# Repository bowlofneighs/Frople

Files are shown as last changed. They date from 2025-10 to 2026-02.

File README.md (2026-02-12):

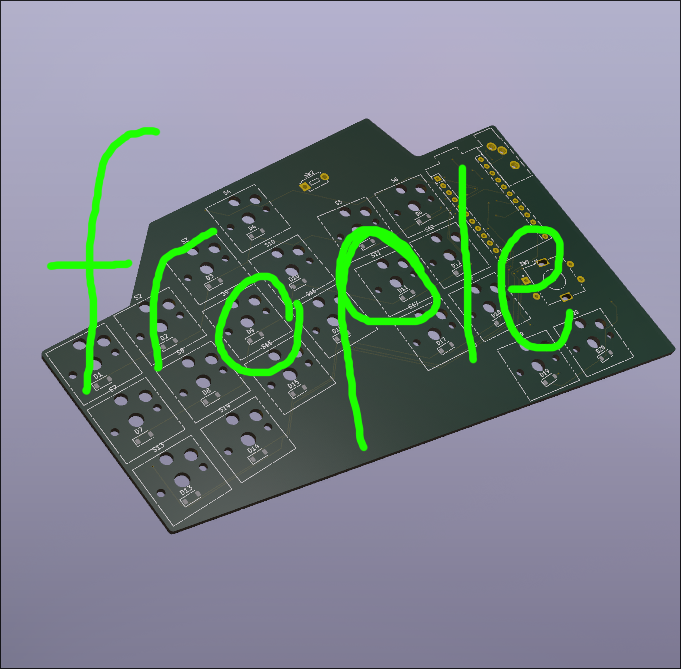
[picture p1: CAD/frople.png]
Frople


# frople
Frople is a split ergonomic keyboard with a 40 key layout. It utilizes a 6x3 main matrix and a 2x1 thumbfan on each side. It uses 2 Arduino Pro Micros as its MCUs and QMK for the firmware. The keys were designed specifically with my hand dimensions in mind, seeing as I took measurements of my finger-length to decide the key stagger. It will take advantage of home-row-mods to allow me to still use my mod keys with such a small key footprint. It also has extra layers to account for the keys that could not fit on the main layer. It uses a TRS cable to communicate between the two halves of the keyboard using serial communcation. In the future it could theoretically be upgraded with a Nice!Nano V2 to allow for wireless communication between the two halves and the computer through BLE (bluetooth low energy). However my current computer does not have bluetooth and the Nice!Nano V2 was more expensive than the Arduino Pro Micro and as such I went with the Pro Micro for the MCU.

I built Frople because I have always been interested by those desktop setup videos, they seemed really cool, and I thought that a split keyboard would be a way to take my desk to the next level. I also made it because I tried out home-row-mods on my normal keyboard using a software called [Kanata](https://github.com/jtroo/kanata) and I found that it really increased my power-useriness and I wanted to take that to the next level. I also am really unsatisfied with my current keyboard, especially the lack of linux compatibal firmware. The final reason I wanted to make a split keyboard is because it sounded like a really fun project to get into hardware design with.



|Item |Description |Quantity |Unit Price CAD |Unit Price USD|Price + tax * quantity (CAD)|Price + tax * quantity (USD)|Shipping CAD |shipping USD|Note |Link |
|---|---|---|---|---|---|---|---|---|---|---|
|Red Choc Switches |Key Switches |40pcs |29.41 + 3.82(tax)|23.93USD |33.23 |23.93 USD |FREE |FREE | |https://www.aliexpress.com/item/1005008751312031.html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 |
|Kailh Hot Swap sockets|Hot swaps |1 (they come in packs of 100 :hs:)|12.87 + 1.67(tax)|10.47 USD |14.54 |10.47 USD |FREE |FREE |even though it was 100 they were still the cheapest |https://www.aliexpress.com/item/1005006625852715.html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 |
|Arduino Pro Micro |MCU |2 |8.99 + 1.16 |7.31 USD |20.3 |14.62 USD |FREE |FREE | |https://www.aliexpress.com/item/1005008804370504.html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 |
|Keycaps |choc low profile ldsa keycaps|4 they come in packs of 10 |5 + 0.65 |4.06 USD |22.6 |16.27 USD |10 + 1.3 |8.13USD |I couldn’t find cheaper unmarked keycaps on aliexpress|https://lowprokb.ca/collections/keycaps/products/ldsa-low-profile-blank-keycaps?variant=44790995878052 |
|SJ1-3533NG |TRS audio jack |2 |3.15 + 0.40 |2.55 USD |7.1 |5.11 USD |5.54 + 0.72 |4.50 USD |LCSC was much more expensive bc shipping |https://www.aliexpress.com/item/1005007818050385.html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{%22order%22%3A%221%22%2C%22eval%22%3A%221%22%2C%22fromPage%22%3A%22search%22}&pdp_npi=6%40dis!CAD!3.15!3.15!!!15.45!15.45!%402101c44517685003345927398e8be0!12000042315760823!sea!CA!0!ABX!1!0!n_tag%3A-29910%3Bd%3A53760023%3Bm03_new_user%3A-29895&curPageLogUid=4tlGIj6PnRZU&utparam-url=scene%3Asearch&#124;query_from%3A&#124;x_object_id%3A1005007818050385&#124;_p_origin_prod%3A|
|PCB |keyboard pcb |1 | |19.00 USD | |19.00 USD | |13.25 USD | |https://hc-cdn.hel1.your-objectstorage.com/s/v3/6d1642395864fce0_image.png |
|ec-11 |rotary encoder |1 They come in packs of 5 |1.62 + 0.21 |1.31 USD |1.83 |1.31 USD |FREE |FREE | |https://www.aliexpress.com/item/1005003824684681.html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 |
| | | | | | | | | | | |
|Total | | | | |99.6 CAD (not including pcb)|90.71 USD |17.56 (Not including pcb)|25.88 |full cost:: 116.59 USD | |

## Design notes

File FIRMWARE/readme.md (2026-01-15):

# frople

frople

*A short description of the keyboard/project*

* Keyboard Maintainer: [Bowlofneighs](https://github.com/Bowlofneighs)
* Hardware Supported: *The PCBs, controllers supported*
* Hardware Availability: *Links to where you can find this hardware*

Make example for this keyboard (after setting up your build environment):

    make frople:default

Flashing example for this keyboard:

    make frople:default:flash

See the [build environment setup](https://docs.qmk.fm/#/getting_started_build_tools) and the [make instructions](https://docs.qmk.fm/#/getting_started_make_guide) for more information. Brand new to QMK? Start with our [Complete Newbs Guide](https://docs.qmk.fm/#/newbs).

## Bootloader

Enter the bootloader in 3 ways:

* **Bootmagic reset**: Hold down the key at (0,0) in the matrix (usually the top left key or Escape) and plug in the keyboard
* **Physical reset button**: Briefly press the button on the back of the PCB - some may have pads you must short instead
* **Keycode in layout**: Press the key mapped to `QK_BOOT` if it is available

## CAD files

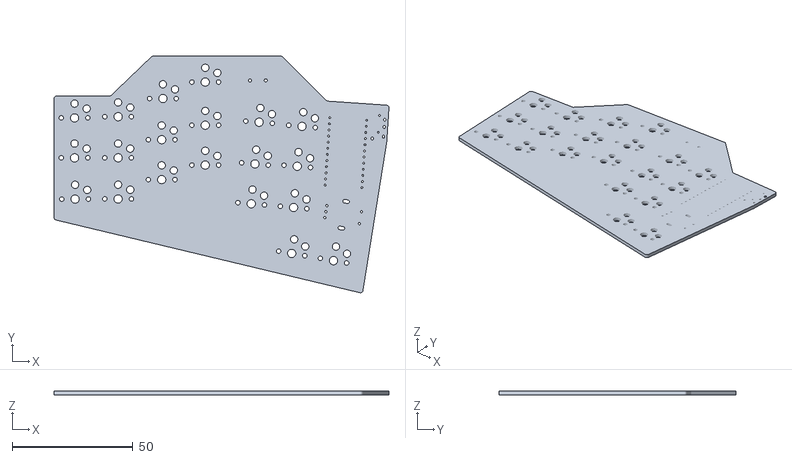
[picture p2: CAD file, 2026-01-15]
Main/MainFill.stl
138.4 x 97.8 x 1.51

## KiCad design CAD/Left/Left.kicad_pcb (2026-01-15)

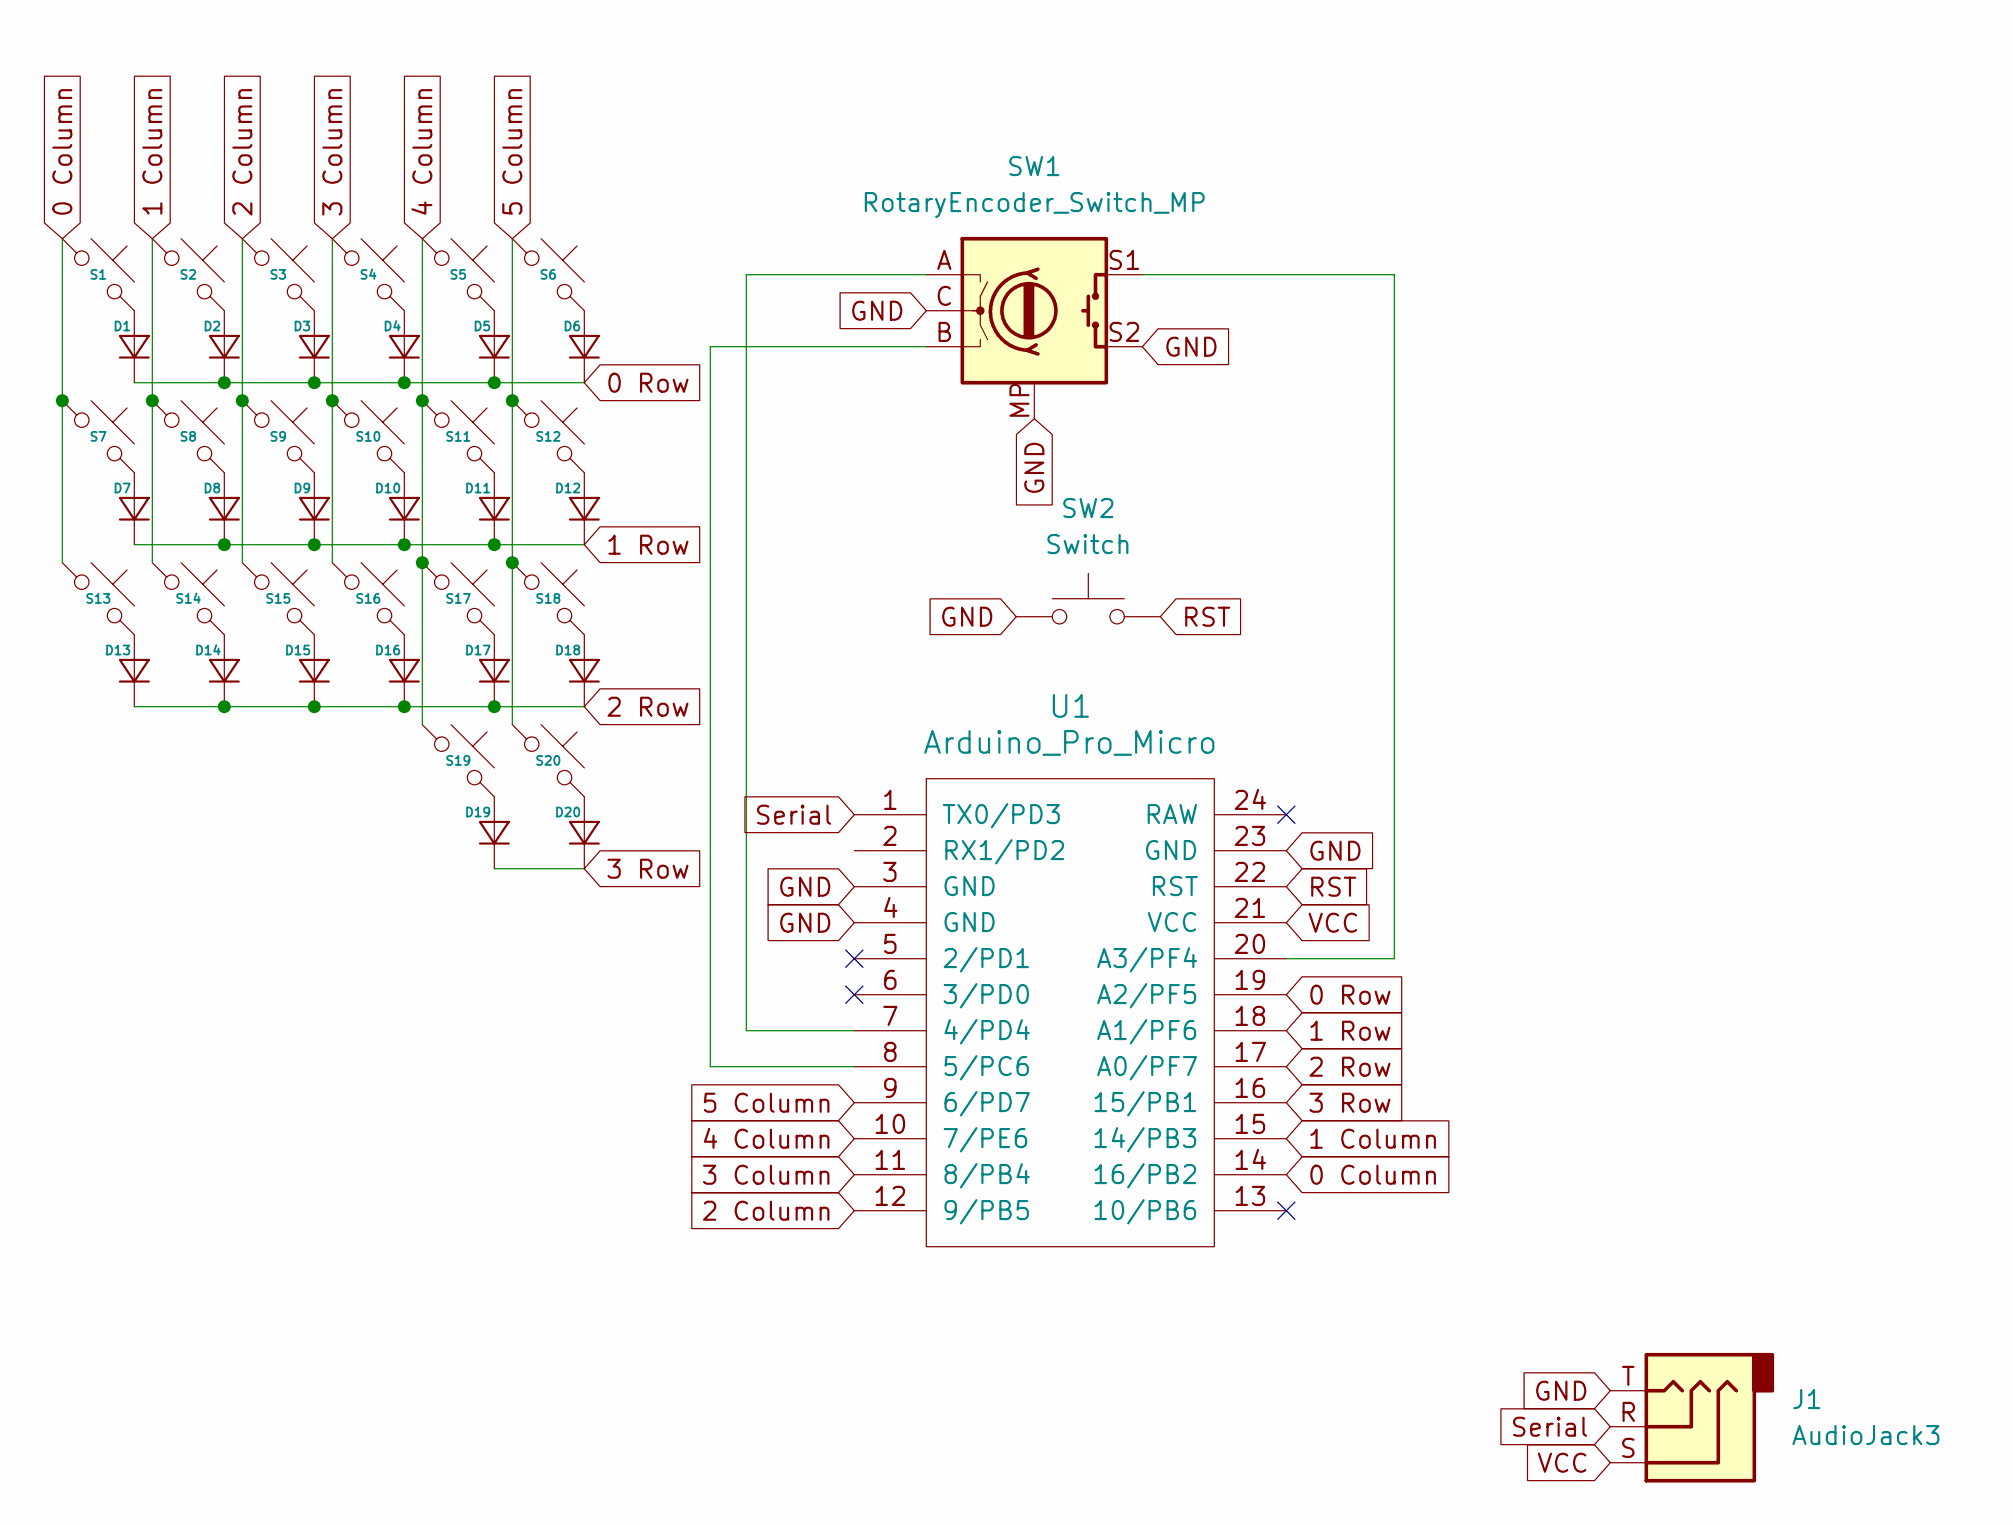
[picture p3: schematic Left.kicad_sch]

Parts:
D1, D2, D3, D4, D5, D6, D7, D8, D9, D10, D11, D12, D13, D14, D15, D16, D17, D18, D19, D20: D_SOD-123
J1: AudioJack3; Jack_3.5mm_CUI_SJ1-3533NG_Horizontal_CircularHoles
S1, S2, S3, S4, S5, S6, S7, S8, S9, S10, S11, S12, S13, S14, S15, S16, S17, S18, S19, S20: Hotswap_Choc_V1
SW1: RotaryEncoder_Switch_MP; RotaryEncoder_Alps_EC11E-Switch_Vertical_H20mm
SW2: Switch; Button_MJTP1243
U1: Arduino_Pro_Micro; Sparkfun_Pro_Micro

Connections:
0 Column: S1.1, S7.1, S13.1, U1.14 (16/PB2)
0 Row: D1.1 (K), D2.1 (K), D3.1 (K), D4.1 (K), D5.1 (K), D6.1 (K), U1.19 (A2/PF5)
1 Column: S2.1, S8.1, S14.1, U1.15 (14/PB3)
1 Row: D7.1 (K), D8.1 (K), D9.1 (K), D10.1 (K), D11.1 (K), D12.1 (K), U1.18 (A1/PF6)
2 Column: S3.1, S9.1, S15.1, U1.12 (9/PB5)
2 Row: D13.1 (K), D14.1 (K), D15.1 (K), D16.1 (K), D17.1 (K), D18.1 (K), U1.17 (A0/PF7)
3 Column: S4.1, S10.1, S16.1, U1.11 (8/PB4)
3 Row: D19.1 (K), D20.1 (K), U1.16 (15/PB1)
4 Column: S5.1, S11.1, S17.1, S19.1, U1.10 (7/PE6)
5 Column: S6.1, S12.1, S18.1, S20.1, U1.9 (6/PD7)
GND: J1.T, SW1.C, SW1.MP, SW1.S2, SW2.1, U1.3 (GND), U1.4 (GND), U1.23 (GND)
unnamed: D1.2 (A), S1.2
unnamed: D2.2 (A), S2.2
unnamed: D3.2 (A), S3.2
unnamed: D4.2 (A), S4.2
unnamed: D5.2 (A), S5.2
unnamed: D6.2 (A), S6.2
unnamed: D7.2 (A), S7.2
unnamed: D8.2 (A), S8.2
unnamed: D9.2 (A), S9.2
unnamed: D10.2 (A), S10.2
unnamed: D11.2 (A), S11.2
unnamed: D12.2 (A), S12.2
unnamed: D13.2 (A), S13.2
unnamed: D14.2 (A), S14.2
unnamed: D15.2 (A), S15.2
unnamed: D16.2 (A), S16.2
unnamed: D17.2 (A), S17.2
unnamed: D18.2 (A), S18.2
unnamed: D19.2 (A), S19.2
unnamed: D20.2 (A), S20.2
unnamed: SW1.A, U1.7 (4/PD4)
unnamed: SW1.B, U1.8 (5/PC6)
unnamed: SW1.S1, U1.20 (A3/PF4)
RST: SW2.2, U1.22 (RST)
Serial: J1.R, U1.1 (TX0/PD3)
VCC: J1.S, U1.21 (VCC)

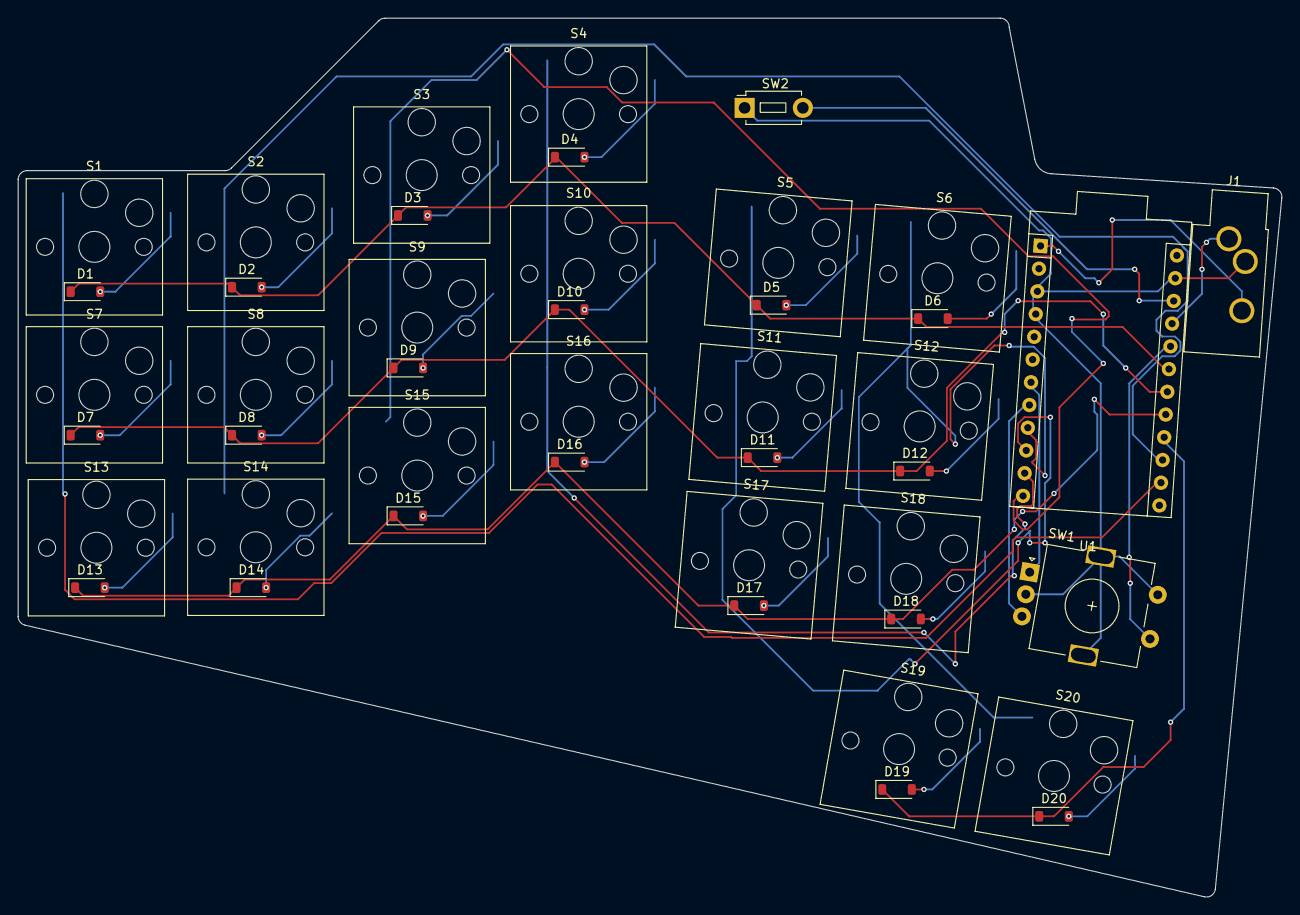
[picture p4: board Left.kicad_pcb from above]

Board: 2 copper layers, 140.9 x 98.0 mm, 44 parts (0 on the bottom side), 37 nets.

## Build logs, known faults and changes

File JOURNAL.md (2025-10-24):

<!--
  ===================    !!READ THIS NOTICE!!   ====================
  DO NOT edit this file manually. Your changes WILL BE OVERWRITTEN!
  This journal is auto generated and updated by Hack Club Blueprint.
  To edit this file, please edit your journal entries on Blueprint.
  ==================================================================
-->

## 10/13/2025 10 AM - Begun Design of key layout  

* Begun keyboard definition in ergogen
* read through FlatFootFox's "Lets Design a Keyboard" introduction and 1/4 of part 1 ( https://flatfootfox.com/ergogen-part1-units-points/ )
* Did research on implementing rotary encoder and/or sliding potentiometer into keyboard design; rotary encoder is feasable, sliding potentiometer is not



## 10/13/2025 5 PM - Designed keymap  





- Defined all the keys in ergogen
- came up with a 40 key layout (6x3 main body 1x2 thumbfan)
- Designed the keymap utilizing home-row-mods and special layers configurable in zmk. 
- I am planning on implementing Hyprland specific keybinds to the keymap to let me navigate my window manager faster

next steps:
- design key layout in ergogen for ergonomics
- brainstorm case designs  

## 10/15/2025 - Designed key layout  

- took measurements of my hands
- did research on how to use said measurements in keyboard layout
- made the keyboard layout using ergogen
- spent a while (not included in time estimate, it was like 30 minutes tho) configuring the GODDAMN PRINTER
- verified that there was no overlap between keys which is a bit harder (not much) than it sounds due to how ergogen renders keys
 

- printed out a couple tests for the key layout to make sure it felt good to type on

WhatsApp Image 2025-10-15 at 22.23.29.jpeg

- figured out how to push to github so now you can see my code on github (also not included in time estimate, it was like 30 minutes also, github CLI hates me)

## 10/16/2025 12 AM - Begun design of pcb  

- did research on part pricing
- started budgeting my build and researching keycaps, switches, encoders etc
- begun design and layout of pcb
- decided on a wired split design using a TRRS cable to communicate between each side
- have ideas for a case (wrist rest mayhaps)
- FlatFootFoxes guide, which i have been using to learn how to use Ergogen, is not of as much help now due to how our designs diverge.
  

## 10/16/2025 10 PM - Preparations for fabrication  

- finalized keyboard design (not including case and other stuff, just the pcb and components that go on said pcb)
- finished wiring up left side of keyboard
- begun making the schematic because ergogen only outputs the pcb file and blueprint needs pcb and schematic file for submission.
-

## 10/18/2025 - SO turns out i cant fully use ergogen  

- uhh, so the docs/faq didnt mention ergogen, turns out the ones on slack are different
- uhhh, so we can use ergogen to design keyboard layout but not pcb
- so i made the schematic from scratch and now im going to do the pcb
- at least it makes designing pcb/schematic/case easier pretty much
- 

## 10/19/2025 - More PCB shenanigans  

- placed the pcb components and lined them up with the layout I laid out in ergogen
- routed the traces, spent like 5 minutes finding the last trace
- the 3d models are all messed up and something is messed up with everything
- idek how to explain it
- everything is on the wrong side of the pcb somehow
 
- to do 
	- fix pcb
	- make right side of pcb
	- prepare for fabrication  

## 10/21/2025 - Fixed the pcb  

- i fixed the pcb
- i really havent gotten much done recently
- i just need to push through to the finish

- todo:
- make right pcb
- set up bom.csv for jlcpcb pcba service
- make some cool renders in blender yay!



idk what happened to the formating on this one :heavysob:

## 10/22/2025 - Placed footprints for right PCB  

- I placed the footprints for the right pcb
- KiCAD crashed and I lost like 10 minutes of progress 
yay autosave
- pcb design being annoying
- trying to find parts for bom.csv from lcsc and jlcpcb is very annoying. I think I am going to have to solder the Arduino  pro-micro myself with help from a friend because i don't have an iron. (yet... tool bag here I come)


## 10/23/2025 - Finished Designing PCB  

All files are ready for fabrication and assembly by JLCPCB I think. I went through their file preparation guide so I think it should all be good. Feeling nervous about finalizing my product but here we go, will be shipping this in the near future



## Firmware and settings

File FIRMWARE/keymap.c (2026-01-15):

#include QMK_KEYBOARD_H

const uint16_t PROGMEM keymaps[][MATRIX_ROWS][MATRIX_COLS] = {
    [0] = LAYOUT(
        KC_ESC,  KC_Q,    KC_W,    KC_E,    KC_R,    KC_T,    KC_Y,    KC_U,    KC_I,    KC_O,    KC_P,    KC_BSPC,
        KC_TAB,  KC_A,    KC_S,    KC_D,    KC_F,    KC_G,    KC_H,    KC_J,    KC_K,    KC_L,    KC_SCLN, KC_QUOT,
        KC_LSFT, KC_Z,    KC_X,    KC_C,    KC_V,    KC_B,    KC_N,    KC_M,    KC_COMM, KC_DOT,  KC_SLSH, KC_RSFT,
        KC_LCTL, KC_LGUI, KC_LALT, MO(1),   KC_SPC,  KC_ENT,  KC_LEFT, KC_DOWN, KC_UP,   KC_RGHT, MO(1),   KC_RCTL
    ),

    [1] = LAYOUT(
        KC_GRV,  KC_1,    KC_2,    KC_3,    KC_4,    KC_5,    KC_6,    KC_7,    KC_8,    KC_9,    KC_0,    KC_DEL,
        KC_TRNS, KC_F1,   KC_F2,   KC_F3,   KC_F4,   KC_F5,   KC_F6,   KC_MINS, KC_EQL,  KC_LBRC, KC_RBRC, KC_BSLS,
        KC_TRNS, KC_F7,   KC_F8,   KC_F9,   KC_F10,  KC_F11,  KC_F12,  KC_TRNS, KC_TRNS, KC_TRNS, KC_TRNS, KC_TRNS,
        KC_TRNS, KC_TRNS, KC_TRNS, KC_TRNS, KC_TRNS, KC_TRNS, KC_HOME, KC_PGDN, KC_PGUP, KC_END,  KC_TRNS, KC_TRNS
    ),

    [2] = LAYOUT(
        QK_BOOT, KC_TRNS, KC_TRNS, KC_TRNS, KC_TRNS, KC_TRNS, KC_TRNS, KC_TRNS, KC_TRNS, KC_TRNS, KC_TRNS, KC_TRNS,
        KC_TRNS, KC_TRNS, KC_TRNS, KC_TRNS, KC_TRNS, KC_TRNS, KC_TRNS, KC_MPRV, KC_MPLY, KC_MNXT, KC_TRNS, KC_TRNS,
        KC_TRNS, KC_TRNS, KC_TRNS, KC_TRNS, KC_TRNS, KC_TRNS, KC_TRNS, KC_MUTE, KC_VOLD, KC_VOLU, KC_TRNS, KC_TRNS,
        KC_TRNS, KC_TRNS, KC_TRNS, KC_TRNS, KC_TRNS, KC_TRNS, KC_TRNS, KC_TRNS, KC_TRNS, KC_TRNS, KC_TRNS, KC_TRNS
    ),

    [3] = LAYOUT(
        KC_TRNS, KC_TRNS, KC_TRNS, KC_TRNS, KC_TRNS, KC_TRNS, KC_TRNS, KC_TRNS, KC_TRNS, KC_TRNS, KC_TRNS, KC_TRNS,
        KC_TRNS, KC_TRNS, KC_TRNS, KC_TRNS, KC_TRNS, KC_TRNS, KC_TRNS, KC_TRNS, KC_TRNS, KC_TRNS, KC_TRNS, KC_TRNS,
        KC_TRNS, KC_TRNS, KC_TRNS, KC_TRNS, KC_TRNS, KC_TRNS, KC_TRNS, KC_TRNS, KC_TRNS, KC_TRNS, KC_TRNS, KC_TRNS,
        KC_TRNS, KC_TRNS, KC_TRNS, KC_TRNS, KC_TRNS, KC_TRNS, KC_TRNS, KC_TRNS, KC_TRNS, KC_TRNS, KC_TRNS, KC_TRNS
    )
};

#if defined(ENCODER_MAP_ENABLE)
const uint16_t PROGMEM encoder_map[][NUM_ENCODERS][NUM_DIRECTIONS] = {
    [0] = { ENCODER_CCW_CW(KC_VOLD, KC_VOLU) },
    [1] = { ENCODER_CCW_CW(KC_BRID, KC_BRIU) },
    [2] = { ENCODER_CCW_CW(KC_MPRV, KC_MNXT) },
    [3] = { ENCODER_CCW_CW(KC_LEFT, KC_RGHT) }
};
#endif

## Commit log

2025-10-16 added pcb.kicad_pcb, updated yaml to include pcb and footprints finalized key layout
    [pcb.kicad_pcb]
2025-10-17 begun creation of schematic, probably willl have to overhaul pcb
    [pcb.kicad_pcb, pcb.kicad_sch]
2025-10-17 cleaned stuff up, going to start pcb from scratch
    [pcb.kicad_pcb, pcb.kicad_sch]
2025-10-26 made the pcbs
    [pcb.kicad_pcb]
2025-12-15 deleted: Productionforrealzthistime (2).zip deleted: kicad-lib-arduino deleted: scottokeebs
2025-12-15 about halfway done left pcb
    [Main.kicad_pcb, Main.kicad_sch, pcb.kicad_pcb]
2025-12-15 figured out footprints and stuff
    [Main.kicad_pcb, Main.kicad_sch]
2025-12-15 finished left PCB
    [Main.kicad_pcb]
2025-12-16 begun work on right PCB, mainly just copying the left one while flipping/rotating a couple things
    [Main.kicad_pcb, Main.kicad_sch]
2025-12-16 fixed previous commit
    [Main.kicad_pcb, Main.kicad_sch]
2025-12-28 changed from I2C communication between the halves to serial because it's easier with QMK
    [Main.kicad_pcb, Main.kicad_sch]
2026-01-15 restructured files
    [Left.kicad_pcb, Left.kicad_sch, LeftCase.blend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]
2026-01-15 created gerbers
    [Left-B_Cu.gbr, Left-B_Mask.gbr, Left-B_Paste.gbr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]
2026-01-15 finished please
    [BOM.csv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]
2026-01-15 revised bom
    [BOM.csv]
2026-02-05 finalized BOM.csv
    [BOM.csv]
